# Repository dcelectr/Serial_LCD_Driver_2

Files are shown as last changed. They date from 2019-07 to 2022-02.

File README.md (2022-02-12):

# Serial_LCD_Driver_2
LCD Screen Driver with 74HC595 (for LCDs with 2x8 header).
This uses the 74HC595 to drive LCD displays such as 1602, 1604, 2002, or 2004 with 5V, GND and three Arduino pins (DIN, CS, and CLK). Compatible with screens that have 2x8 male header.
It is recommended to use a 2x8 male header on the LCD and 1x8 female socket on the Serial_LCD_Driver_2.
Note that in the KiCad files male header is used (although the 3D .png rendering shows how the female socket should be populated), because I wanted to have pin for pin maping (ignore the 3D rendering in the KiCad files).
The LED (D1) and R2 are optional. You can populate for diagnostics (test the hardware), or connect a panel LED with wires to the Serial_LCD_Driver_2.
It is recommended to use a resistance value for R2 no lower than 470 Ohms (preferably use 1K with high efficiency LEDs).
The Q1 is used to provide current for the LCD back-light, so that the 74HC595 does not bear the burden to provide the required back-light current (some LCD back-lights draw as much as 200mA). The R1 can be adjusted (1K to 10K) to achieve Q1 saturation for or reduce the current to a desired brightness.
This design has been built and tested with the code provided in the Serial_LCD_Driver repository. It works! 
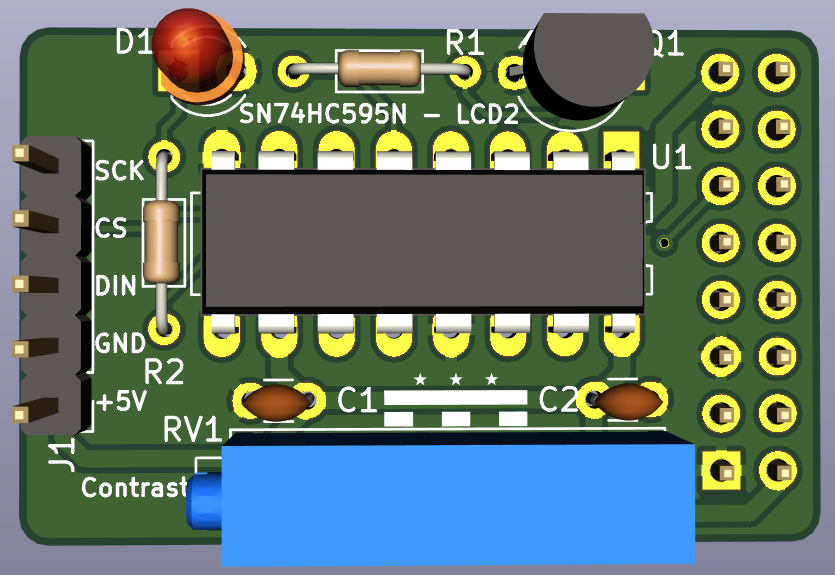
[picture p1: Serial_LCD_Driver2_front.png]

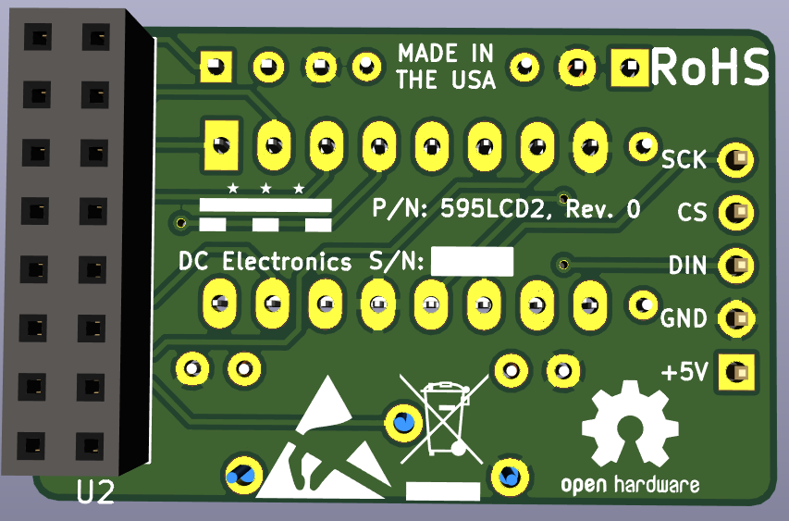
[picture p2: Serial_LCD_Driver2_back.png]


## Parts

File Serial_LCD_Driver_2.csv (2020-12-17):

Reference | Quantity | Value | Part Number | Footprint | Datasheet
C1 | 1 | 100nF | C320C104K5R5TA7317 | Capacitor_THT:C_Disc_D3.0mm_W1.6mm_P2.50mm | ~
C2 | 1 | 10nF | C315C103K5R5TA | Capacitor_THT:C_Disc_D3.0mm_W1.6mm_P2.50mm | ~
D1 | 1 | LED | 3mm LED | LED_THT:LED_D3.0mm | ~
J1 | 1 | Conn_01x05_Male | 1x5 male header | Connector_PinHeader_2.54mm:PinHeader_1x05_P2.54mm_Vertical | ~
Q1 | 1 | BC547 | BC547 | Package_TO_SOT_THT:TO-92_Inline_Wide | http://www.fairchildsemi.com/ds/BC/BC547.pdf
R1 | 1 | 4K7 | 1/8W 4.7 kOhms | Resistor_THT:R_Axial_DIN0204_L3.6mm_D1.6mm_P7.62mm_Horizontal | ~
R2 | 1 | 470 | 1/8W 470 Ohms | Resistor_THT:R_Axial_DIN0204_L3.6mm_D1.6mm_P7.62mm_Horizontal | ~
RV1 | 1 | 10K | 3009P-1-103LF | Potentiometer_THT:Potentiometer_Bourns_3009P_Horizontal | ~
U1 | 1 | 74HC595 | SN74HC595N or 74HCT595N | Package_DIP:DIP-16_W7.62mm_LongPads | http://www.ti.com/lit/ds/symlink/sn74hc595.pdf
U2 | 1 | RC1602A | PPPC161LFBN-RC | Connector_PinHeader_2.54mm:PinHeader_2x08_P2.54mm_Vertical | http://www.raystar-optronics.com/down.php?ProID=18

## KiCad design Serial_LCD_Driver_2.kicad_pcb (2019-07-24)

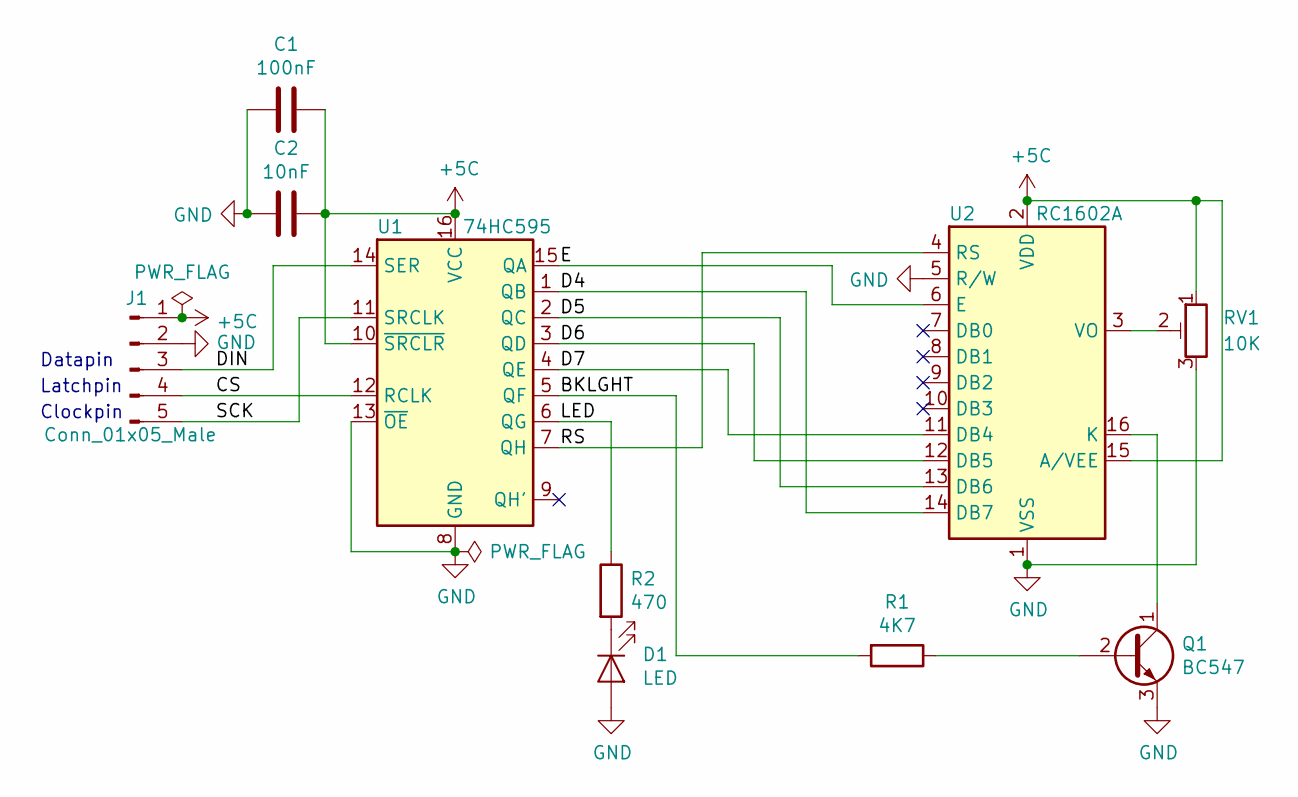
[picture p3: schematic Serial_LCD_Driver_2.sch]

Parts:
C1: 100nF; C_Disc_D3.0mm_W1.6mm_P2.50mm
C2: 10nF; C_Disc_D3.0mm_W1.6mm_P2.50mm
D1: LED; LED_D3.0mm
J1: Conn_01x05_Male; PinHeader_1x05_P2.54mm_Vertical
Q1: BC547; TO-92_Inline_Wide
R1: 4K7; R_Axial_DIN0204_L3.6mm_D1.6mm_P7.62mm_Horizontal
R2: 470; R_Axial_DIN0204_L3.6mm_D1.6mm_P7.62mm_Horizontal
RV1: 10K; Potentiometer_Bourns_3009P_Horizontal
U1: 74HC595; DIP-16_W7.62mm_LongPads
U2: RC1602A; PinHeader_2x08_P2.54mm_Vertical

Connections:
+5C: C1.1, C2.1, J1.1, RV1.1, U1.10 (~SRCLR), U1.16 (VCC), U2.2 (VDD), U2.15 (A/VEE)
/BKLGHT: R1.2, U1.5 (QF)
/CS: J1.4, U1.12 (RCLK)
/D4: U1.1 (QB), U2.14 (DB7)
/D5: U1.2 (QC), U2.13 (DB6)
/D6: U1.3 (QD), U2.12 (DB5)
/D7: U1.4 (QE), U2.11 (DB4)
/DIN: J1.3, U1.14 (SER)
/E: U1.15 (QA), U2.6 (E)
/LED: R2.1, U1.6 (QG)
/RS: U1.7 (QH), U2.4 (RS)
/SCK: J1.5, U1.11 (SRCLK)
GND: C1.2, C2.2, D1.2 (A), J1.2, Q1.3 (E), RV1.3, U1.8 (GND), U1.13 (~OE), U2.1 (VSS), U2.5 (R/W)
unnamed: D1.1 (K), R2.2
unnamed: Q1.1 (C), U2.16 (K)
unnamed: Q1.2 (B), R1.1
unnamed: RV1.2, U2.3 (VO)

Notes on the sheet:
Datapin
Latchpin
Clockpin

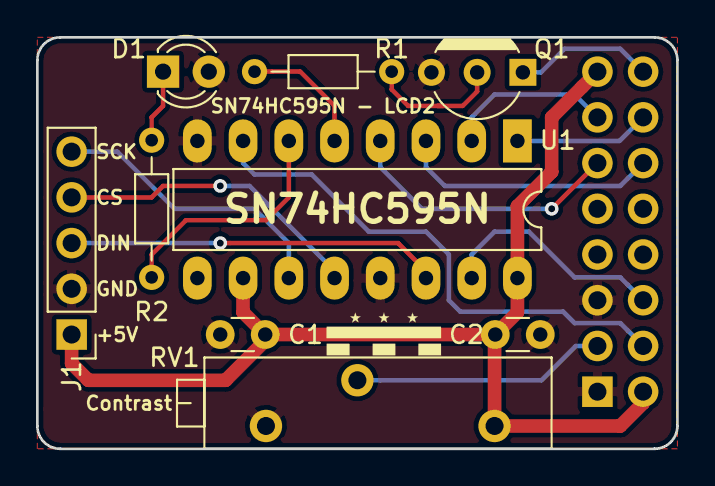
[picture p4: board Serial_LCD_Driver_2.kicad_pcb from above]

Board: 2 copper layers, 35.6 x 22.9 mm, 10 parts (1 on the bottom side), 17 nets.

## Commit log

2019-07-24 KiCad Files
    [Serial_LCD_Driver_2.kicad_pcb, Serial_LCD_Driver_2.sch]
2020-12-17 Added Bill of Materials CSV file
    [Serial_LCD_Driver_2.csv]
